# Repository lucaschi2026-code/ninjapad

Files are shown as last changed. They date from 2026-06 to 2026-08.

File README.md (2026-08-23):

# Ninjapad
Ninjapad is a macropad with 9 keys, 1 rotary encoder, and an 0.91 inch OLED display. It uses a custom PCB, 3D printed case, and QMK firmware. OLED features different animations inspired by Naruto.

[🎬Build Montage🎬](https://www.youtube.com/shorts/z15oCYiYoOs)

[🎬Showcase Edit🎬](https://www.youtube.com/shorts/6WCUAFyBArM)

[🎬Full Build + Demo🎬](https://www.youtube.com/watch?v=4l7bW2d6SSs)





## Features

- 9 key + rotary encoder layout
- [3D printed case](/Production)
- [3D printed rotary knob](/Production/Rotary_Keycap.step)
- [Custom PCB](/PCB)
- 128x32 OLED Display
- [QMK firmware (keys, rotary encoder, OLED can be programmed to anything)](/Firmware)
- 🎬Naruto inspired animations🎬

https://github.com/user-attachments/assets/e3caf68b-d00f-4336-b8fd-c6721da46e56

## Schematic

- Features a matrix to save pins and diodes to prevent ghosting.
  


## PCB

- Features 2 vias and flipped diodes so that they attach under the PCB.
  


## Case Components
Top Shell:

- 4 through holes to secure to bottom shell. Underside features 4 insert pockets for heat set inserts to secure PCB. 



Bottom Shell:

- 4 insert pockets and a cutout for USB cable.



The shells are attached with the top over the bottom. The shells are secured with 4 M3x16mm screws through heat set inserts on the bottom shell.
## BOM
| Item | Qty |
|---|-----|
| Seeed XIAO RP2040 | 1 |
| Through-hole 1N4148 Diode | 9 |
| MX-Style Switch | 9 |
| EC11 Rotary Encoder | 1 |
| 0.91 inch OLED Display | 1 |
| White Blank DSA Keycap | 9 |
| M3x16mm Screw | 4 |
| M3x5mmx4mm Heatset Insert | 8 |
| M3x5mm Screw | 4 |
| Case (top and bottom shell) | 1 |
| Custom PCB | 1 |

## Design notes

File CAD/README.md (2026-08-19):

# 3D Models from:
- Seeed XIAO RP2040: https://grabcad.com/library/seeed-studio-xiao-rp2040-1
- Rotary Encoder: https://grabcad.com/library/rotary-encoder-17
- 0.91 Inch OLED: https://grabcad.com/library/oled-0-91-128x32-1
- Keycaps: https://grabcad.com/library/dsa-keycap-for-cherry-mx-switches-1
- Cherry MX Switches: https://grabcad.com/library/cherry-mx-switches-mx-1
- Konoha Engraving: https://www.svgrepo.com/svg/512533/naruto-119

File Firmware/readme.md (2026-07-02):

# ninjapad

ninjapad

*A short description of the keyboard/project*

* Keyboard Maintainer: [Lucas Chi](https://github.com/lucaschi2026-code)
* Hardware Supported: *The PCBs, controllers supported*
* Hardware Availability: *Links to where you can find this hardware*

Make example for this keyboard (after setting up your build environment):

    make ninjapad:default

Flashing example for this keyboard:

    make ninjapad:default:flash

See the [build environment setup](https://docs.qmk.fm/#/getting_started_build_tools) and the [make instructions](https://docs.qmk.fm/#/getting_started_make_guide) for more information. Brand new to QMK? Start with our [Complete Newbs Guide](https://docs.qmk.fm/#/newbs).

## Bootloader

Enter the bootloader in 3 ways:

* **Bootmagic reset**: Hold down the key at (0,0) in the matrix (usually the top left key or Escape) and plug in the keyboard
* **Physical reset button**: Briefly press the button on the back of the PCB - some may have pads you must short instead
* **Keycode in layout**: Press the key mapped to `QK_BOOT` if it is available

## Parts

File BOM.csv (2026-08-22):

Item # | Quantity Required | Component Description
1 | 1 | Seeed XIAO RP2040
2 | 9 | Through-hole 1N4148 Diode
3 | 9 | MX-Style Switch
4 | 1 | EC11 Rotary Encoder
5 | 1 | 0.91 inch OLED Display
6 | 9 | White Blank DSA Keycap
7 | 4 | M3x16mm Screw
8 | 8 | M3x5mmx4mm Heatset Insert
9 | 4 | M3x5mm Screw
10 | 1 | 3D printed Case (Top and bottom shell)
11 | 1 | Custom PCB

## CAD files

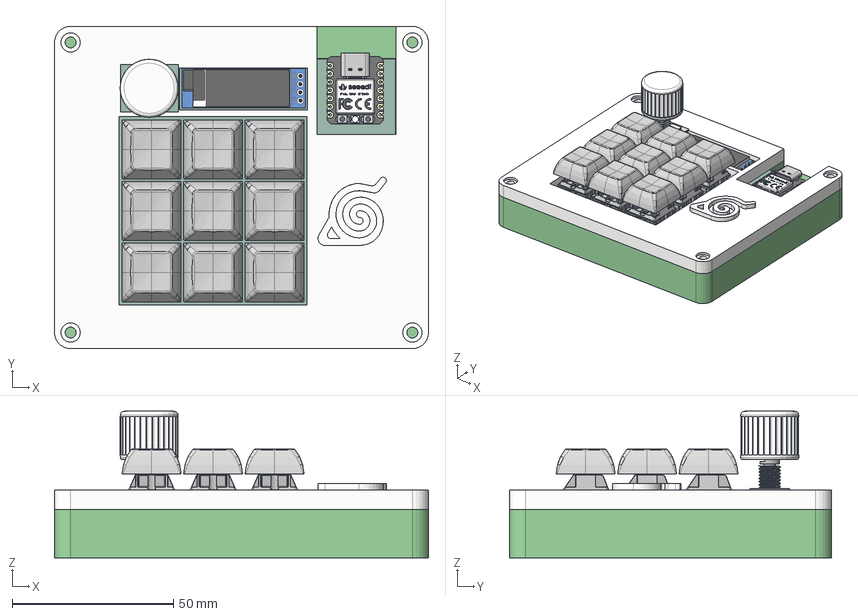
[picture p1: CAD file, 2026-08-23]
CAD/Ninjapad.step
115.9 x 99.9 x 45.4 mm
D_DO-35_SOD27_P7.62mm_Horizontal_1 x 9
Macropad_PCB

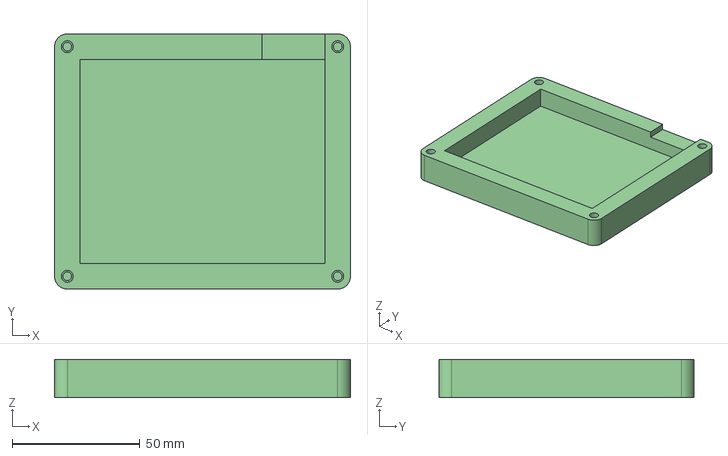
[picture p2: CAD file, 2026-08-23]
Production/Bottom_Shell.step
115.9 x 99.9 x 15.0 mm

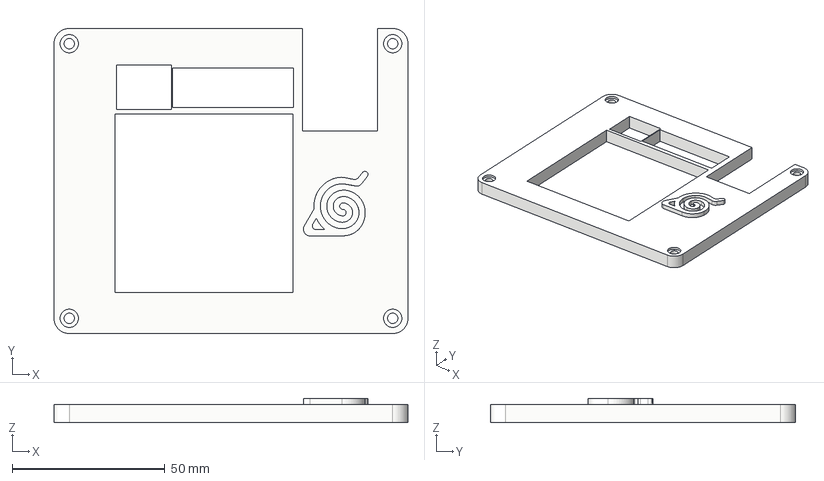
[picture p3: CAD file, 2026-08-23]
Production/Top_Shell.step
115.9 x 99.9 x 8.00 mm

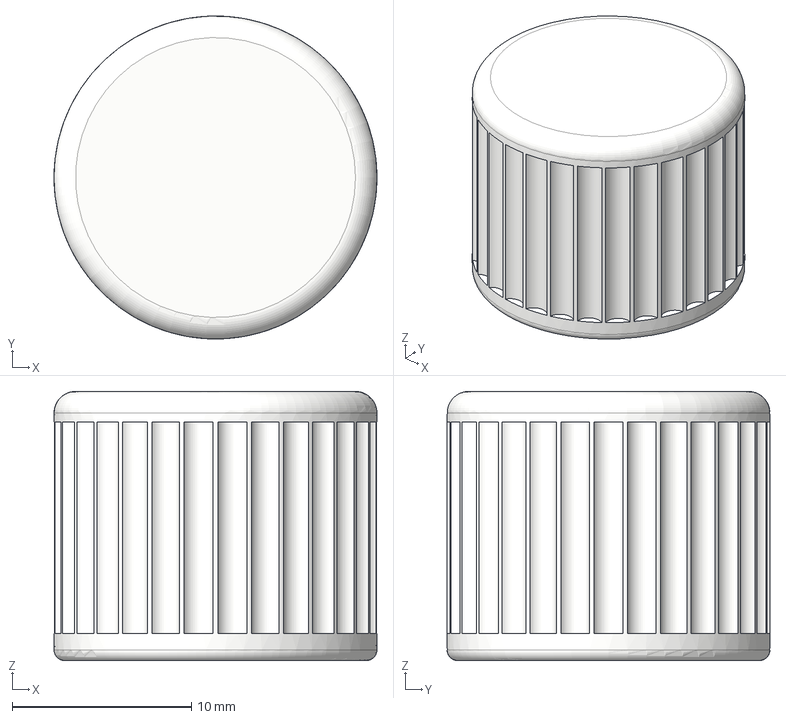
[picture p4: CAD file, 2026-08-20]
Production/Rotary_Keycap.step
18.0 x 18.0 x 15.0 mm

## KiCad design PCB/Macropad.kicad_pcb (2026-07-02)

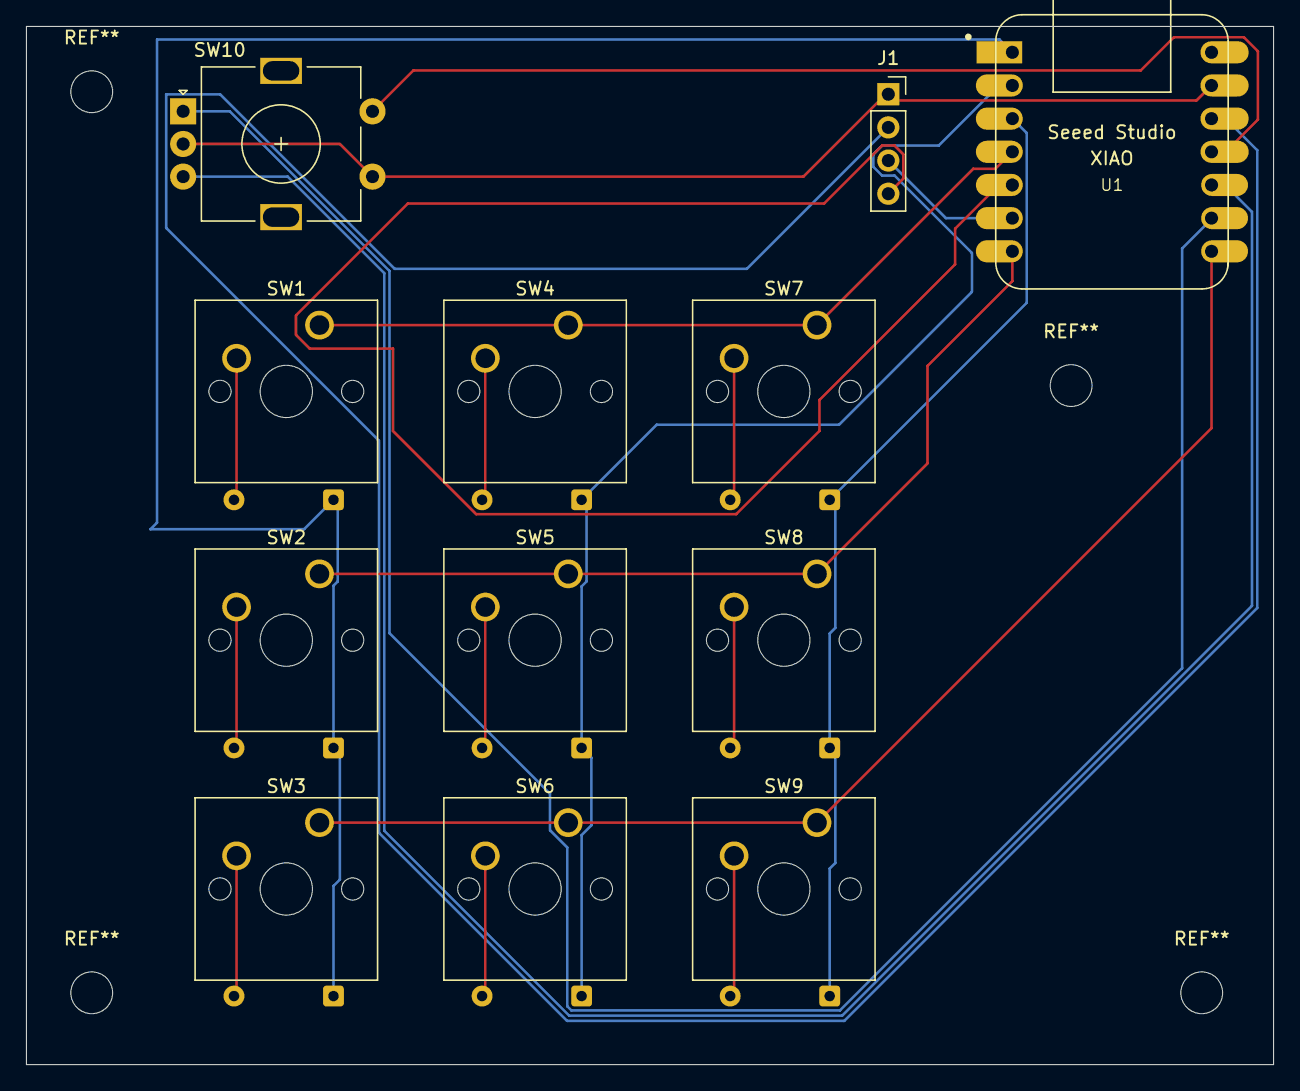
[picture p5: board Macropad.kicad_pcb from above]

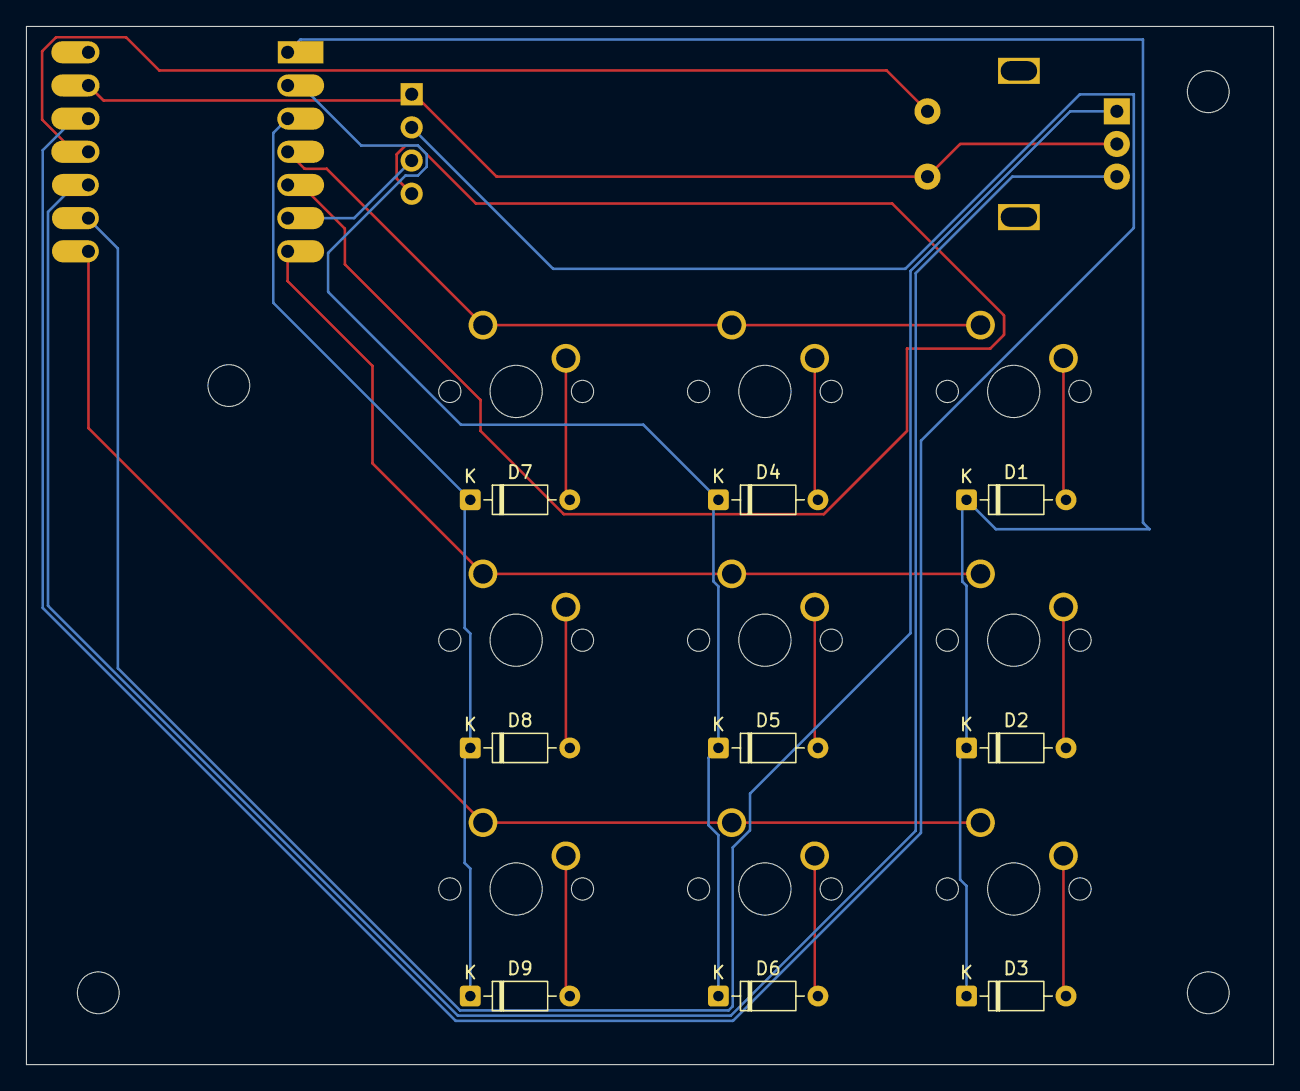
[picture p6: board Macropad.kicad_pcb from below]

Board: 2 copper layers, 95.5 x 79.5 mm, 21 parts (9 on the bottom side), 22 nets.

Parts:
D1, D2, D3, D4, D5, D6, D7, D8, D9: 1N4148; D_DO-35_SOD27_P7.62mm_Horizontal
J1: Conn_01x04_Pin; PinSocket_1x04_P2.54mm_Vertical
SW1, SW2, SW3, SW4, SW5, SW6, SW7, SW8, SW9: SW_Push; SW_Cherry_MX_1.00u_PCB
SW10: RotaryEncoder_Switch; RotaryEncoder_Alps_EC11E-Switch_Vertical_H20mm
U1: MOUDLE-SEEEDUINO-XIAO; XIAO-Generic-Hybrid-14P-2.54-21X17.8MM

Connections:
/3V3: J1.2, U1.12 (3V3)
/Col 1: SW1.1, SW4.1, SW7.1, U1.4 (PA11_A3_D3)
/Col 2: SW2.1, SW5.1, SW8.1, U1.7 (PB08_A6_D6_TX)
/Col 3: SW3.1, SW6.1, SW9.1, U1.8 (PB09_A7_D7_RX)
/ENC_A: SW10.A, U1.9 (PA7_A8_D8_SCK)
/ENC_B: SW10.B, U1.10 (PA5_A9_D9_MISO)
/ENC_SW: SW10.S2, U1.11 (PA6_A10_D10_MOSI)
/Row 1: D1.1 (K), D2.1 (K), D3.1 (K), U1.1 (PA02_A0_D0)
/Row 2: D4.1 (K), D5.1 (K), D6.1 (K), U1.2 (PA4_A1_D1)
/Row 3: D7.1 (K), D8.1 (K), D9.1 (K), U1.3 (PA10_A2_D2)
/SCL: J1.3, U1.6 (PA9_A5_D5_SCL)
/SDA: J1.4, U1.5 (PA8_A4_D4_SDA)
GND: J1.1, SW10.C, SW10.S1, U1.13 (GND)
unnamed: D1.2 (A), SW1.2
unnamed: D2.2 (A), SW2.2
unnamed: D3.2 (A), SW3.2
unnamed: D4.2 (A), SW4.2
unnamed: D5.2 (A), SW5.2
unnamed: D6.2 (A), SW6.2
unnamed: D7.2 (A), SW7.2
unnamed: D8.2 (A), SW8.2
unnamed: D9.2 (A), SW9.2

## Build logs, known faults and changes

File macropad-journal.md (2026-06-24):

# Macropad — Journal Export

- Exported at: 2026-06-24T17:44:00Z
- Project ID: 4809
- Entries: 1

## Entry 1
- ID: 16149
- Author: lucas.chi2026
- Created At: 2026-06-24T14:20:59Z

### Content

Started building the case for my marcopad.
What went well:
- I am getting more comfortable with Fusion

What I'm stuck on:
- I am struggling with extruding the correct faces.



### Recording Links

- https://lookout.hackclub.com/api/media/7a1cafa0-7c11-46e8-8add-b0deb8a1b123/video.mp4

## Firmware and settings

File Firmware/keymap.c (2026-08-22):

#include QMK_KEYBOARD_H

const uint16_t PROGMEM keymaps[][MATRIX_ROWS][MATRIX_COLS] = {
    // Note that columns top to bottom here are the rows left to right on physical board.
    // Physical Layout:
    // LCS(KC_M),  KC_F, LCTL(KC_S)
    // KC_E, KC_Q, KC_M
    // KC_S, LCTL(KC_Z), KC_V
    [0] = LAYOUT(
        LCS(KC_M),      KC_E,           KC_S,
        KC_F,           KC_Q,           LCTL(KC_Z),
        LCTL(KC_S),     KC_M,           KC_V
    )
};

/* ======================================================================
 * OLED: 128x32 SSD1306
 *
 *   keypress        -> a shuriken spins across the screen, left to right.
 *                      Spamming keys launches more of them at once.
 *   encoder CW      -> volume up   + kunai thrown left to right
 *   encoder CCW     -> volume down + kunai thrown right to left
 *   encoder press   -> mute        + summoning jutsu
 *   idle            -> NINJAPAD filling the screen
 * ==================================================================== */

#ifdef OLED_ENABLE

/* art_ninjapad: 128x32, 1 frame(s), stride 16 */
static const uint8_t PROGMEM art_ninjapad[512] = {
    0xF8, 0x1F, 0x0F, 0x87, 0xE0, 0x78, 0x7C, 0x01, 0xF8, 0x07, 0xFF, 0x00, 0x7E, 0x01, 0xFF, 0xC0,
    0xFC, 0x1F, 0x0F, 0x87, 0xE0, 0x78, 0x7C, 0x03, 0xF8, 0x07, 0xFF, 0x80, 0x7E, 0x01, 0xFF, 0xF0,
    0xFC, 0x1F, 0x0F, 0x87, 0xE0, 0x78, 0x7C, 0x03, 0xF8, 0x07, 0xFF, 0xC0, 0xFE, 0x01, 0xFF, 0xF8,
    0xFE, 0x1F, 0x0F, 0x87, 0xF0, 0x78, 0x7C, 0x03, 0xF8, 0x07, 0xFF, 0xE0, 0xFF, 0x01, 0xFF, 0xFC,
    0xFE, 0x1F, 0x0F, 0x87, 0xF0, 0x78, 0x7C, 0x03, 0xFC, 0x07, 0xFF, 0xE0, 0xFF, 0x01, 0xFF, 0xFC,
    0xFE, 0x1F, 0x0F, 0x87, 0xF8, 0x78, 0x7C, 0x07, 0xFC, 0x07, 0xC3, 0xF0, 0xFF, 0x01, 0xF0, 0xFE,
    0xFF, 0x1F, 0x0F, 0x87, 0xF8, 0x78, 0x7C, 0x07, 0xFC, 0x07, 0xC1, 0xF1, 0xFF, 0x01, 0xF0, 0x7E,
    0xFF, 0x1F, 0x0F, 0x87, 0xF8, 0x78, 0x7C, 0x07, 0xBC, 0x07, 0xC1, 0xF1, 0xFF, 0x81, 0xF0, 0x3E,
    0xFF, 0x1F, 0x0F, 0x87, 0xFC, 0x78, 0x7C, 0x07, 0xBE, 0x07, 0xC1, 0xF1, 0xEF, 0x81, 0xF0, 0x1F,
    0xFF, 0x9F, 0x0F, 0x87, 0xFC, 0x78, 0x7C, 0x0F, 0xBE, 0x07, 0xC1, 0xF1, 0xE7, 0x81, 0xF0, 0x1F,
    0xF7, 0x9F, 0x0F, 0x87, 0xDC, 0x78, 0x7C, 0x0F, 0x9E, 0x07, 0xC3, 0xF3, 0xE7, 0x81, 0xF0, 0x1F,
    0xF3, 0xDF, 0x0F, 0x87, 0xDE, 0x78, 0x7C, 0x0F, 0x1E, 0x07, 0xC7, 0xE3, 0xE7, 0xC1, 0xF0, 0x1F,
    0xF3, 0xDF, 0x0F, 0x87, 0xDE, 0x78, 0x7C, 0x0F, 0x1F, 0x07, 0xFF, 0xE3, 0xC7, 0xC1, 0xF0, 0x1F,
    0xF3, 0xDF, 0x0F, 0x87, 0xCE, 0x78, 0x7C, 0x1F, 0x1F, 0x07, 0xFF, 0xC3, 0xC3, 0xC1, 0xF0, 0x1F,
    0xF1, 0xFF, 0x0F, 0x87, 0xCF, 0x78, 0x7C, 0x1F, 0x0F, 0x07, 0xFF, 0xC7, 0xC3, 0xC1, 0xF0, 0x1F,
    0xF1, 0xFF, 0x0F, 0x87, 0xCF, 0x78, 0x7C, 0x1F, 0x0F, 0x87, 0xFF, 0x07, 0xC3, 0xE1, 0xF0, 0x1F,
    0xF1, 0xFF, 0x0F, 0x87, 0xC7, 0xF8, 0x7C, 0x1F, 0xFF, 0x87, 0xC0, 0x07, 0xFF, 0xE1, 0xF0, 0x1F,
    0xF0, 0xFF, 0x0F, 0x87, 0xC7, 0xF8, 0x7C, 0x3F, 0xFF, 0x87, 0xC0, 0x07, 0xFF, 0xE1, 0xF0, 0x3F,
    0xF0, 0xFF, 0x0F, 0x87, 0xC7, 0xF8, 0x7C, 0x3F, 0xFF, 0x87, 0xC0, 0x0F, 0xFF, 0xF1, 0xF0, 0x3E,
    0xF0, 0x7F, 0x0F, 0x87, 0xC3, 0xF8, 0x7C, 0x3F, 0xFF, 0xC7, 0xC0, 0x0F, 0xFF, 0xF1, 0xF0, 0xFE,
    0xF0, 0x7F, 0x0F, 0x87, 0xC3, 0xF8, 0x7C, 0x3F, 0xFF, 0xC7, 0xC0, 0x0F, 0xFF, 0xF1, 0xFF, 0xFC,
    0xF0, 0x7F, 0x0F, 0x87, 0xC1, 0xF8, 0x7C, 0x7C, 0x07, 0xC7, 0xC0, 0x1F, 0x00, 0xF1, 0xFF, 0xFC,
    0xF0, 0x3F, 0x0F, 0x87, 0xC1, 0xF8, 0x7C, 0x7C, 0x03, 0xC7, 0xC0, 0x1F, 0x00, 0xF9, 0xFF, 0xF8,
    0xF0, 0x3F, 0x0F, 0x87, 0xC1, 0xF8, 0x7C, 0x7C, 0x03, 0xE7, 0xC0, 0x1F, 0x00, 0xF9, 0xFF, 0xF0,
    0xF0, 0x3F, 0x0F, 0x87, 0xC0, 0xF8, 0x7C, 0xF8, 0x03, 0xE7, 0xC0, 0x1E, 0x00, 0xF9, 0xFF, 0xC0,
    0x00, 0x00, 0x00, 0x00, 0x00, 0x00, 0x7C, 0x00, 0x00, 0x00, 0x00, 0x00, 0x00, 0x00, 0x00, 0x00,
    0x00, 0x00, 0x00, 0x00, 0x00, 0x00, 0xFC, 0x00, 0x00, 0x00, 0x00, 0x00, 0x00, 0x00, 0x00, 0x00,
    0x00, 0x00, 0x00, 0x00, 0x00, 0x03, 0xF8, 0x00, 0x00, 0x00, 0x00, 0x00, 0x00, 0x00, 0x00, 0x00,
    0x00, 0x00, 0x00, 0x00, 0x00, 0x03, 0xF8, 0x00, 0x00, 0x00, 0x00, 0x00, 0x00, 0x00, 0x00, 0x00,
    0x00, 0x00, 0x00, 0x00, 0x00, 0x03, 0xF0, 0x00, 0x00, 0x00, 0x00, 0x00, 0x00, 0x00, 0x00, 0x00,
    0x00, 0x00, 0x00, 0x00, 0x00, 0x03, 0xF0, 0x00, 0x00, 0x00, 0x00, 0x00, 0x00, 0x00, 0x00, 0x00,
    0x00, 0x00, 0x00, 0x00, 0x00, 0x03, 0xC0, 0x00, 0x00, 0x00, 0x00, 0x00, 0x00, 0x00, 0x00, 0x00,
};

/* art_shuriken: 15x15, 4 frame(s), stride 2 */
static const uint8_t PROGMEM art_shuriken[4][30] = {
    {
        0x00, 0x00,
        0x01, 0x00,
        0x01, 0x00,
        0x03, 0x80,
        0x03, 0x80,
        0x07, 0xC0,
        0x0E, 0xF0,
        0x7C, 0x7C,
        0x1E, 0xF0,
        0x07, 0xC0,
        0x03, 0x80,
        0x03, 0x80,
        0x01, 0x00,
        0x01, 0x00,
        0x00, 0x00,
    },
    {
        0x00, 0x00,
        0x00, 0x00,
        0x04, 0x00,
        0x06, 0x00,
        0x07, 0x00,
        0x07, 0xF8,
        0x06, 0xF0,
        0x0C, 0x60,
        0x1E, 0xC0,
        0x3F, 0xC0,
        0x01, 0xC0,
        0x00, 0xC0,
        0x00, 0x40,
        0x00, 0x00,
        0x00, 0x00,
    },
    {
        0x00, 0x00,
        0x00, 0x00,
        0x00, 0x00,
        0x18, 0x30,
        0x1C, 0xF0,
        0x0F, 0xE0,
        0x0E, 0xC0,
        0x04, 0x40,
        0x06, 0xE0,
        0x0F, 0xE0,
        0x1E, 0x70,
        0x18, 0x30,
        0x00, 0x00,
        0x00, 0x00,
        0x00, 0x00,
    },
    {
        0x00, 0x00,
        0x00, 0x00,
        0x00, 0x40,
        0x00, 0xC0,
        0x01, 0xC0,
        0x3F, 0xC0,
        0x1E, 0xC0,
        0x0C, 0x60,
        0x06, 0xF0,
        0x07, 0xF8,
        0x07, 0x00,
        0x06, 0x00,
        0x04, 0x00,
        0x00, 0x00,
        0x00, 0x00,
    },
};

/* art_kunai: 27x11, 1 frame(s), stride 4 */
static const uint8_t PROGMEM art_kunai[44] = {
    0x00, 0x00, 0x00, 0x00,
    0x00, 0x00, 0x00, 0x00,
    0x38, 0x01, 0x80, 0x00,
    0x7C, 0x03, 0xF0, 0x00,
    0x47, 0xFF, 0xFE, 0x00,
    0xC7, 0xFF, 0xFF, 0xC0,
    0x47, 0xFF, 0xFF, 0x00,
    0x7C, 0x03, 0xF8, 0x00,
    0x38, 0x01, 0x80, 0x00,
    0x00, 0x00, 0x00, 0x00,
    0x00, 0x00, 0x00, 0x00,
};
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

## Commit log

2026-07-02 Enhance README with detailed project information
    Expanded project description and added images for schematic, PCB, case components, and BOM.
2026-07-02 Update README with shell assembly details
    Added information about shell assembly and screws.
2026-07-02 Add BOM.csv with components and quantities
    [BOM.csv]
2026-08-19 Replace images and update BOM quantities
    Updated images and BOM details in README.md.
2026-08-19 Update quantity for M3x16mm Screw in BOM
    [BOM.csv]
2026-08-22 Enhance README with schematic and PCB features
    Added features descriptions for schematic and PCB sections.
2026-08-22 Fix typo in README regarding heat set inserts
2026-08-22 Add 3D printed rotary knob feature to README
2026-08-22 Link 3D printed rotary knob in README
2026-08-22 Fix link to 3D printed rotary knob in README
2026-08-22 Fix link for 3D printed rotary knob
    Updated the link for the 3D printed rotary knob in the features section.
2026-08-22 Fix link to 3D printed rotary knob
2026-08-22 Fix link format for 3D printed rotary knob
2026-08-22 Fix link for rotary knob in README
    Updated link for the 3D printed rotary knob in README.
2026-08-22 Rename Rotary Keycap.step to Rotary_Keycap.step
    [Rotary_Keycap.step]
2026-08-22 Add Custom PCB to parts list in README
2026-08-22 Add Custom PCB entry to BOM.csv
    [BOM.csv]
2026-08-22 Swap quantities for M3 screws and inserts in BOM
    [BOM.csv]
